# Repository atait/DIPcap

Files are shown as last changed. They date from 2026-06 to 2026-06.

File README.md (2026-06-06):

# DIPcap

A variable capacitor bank built from DIP switches. Six decades of coverage (1 nF to 1 mF) for under $10 to build.

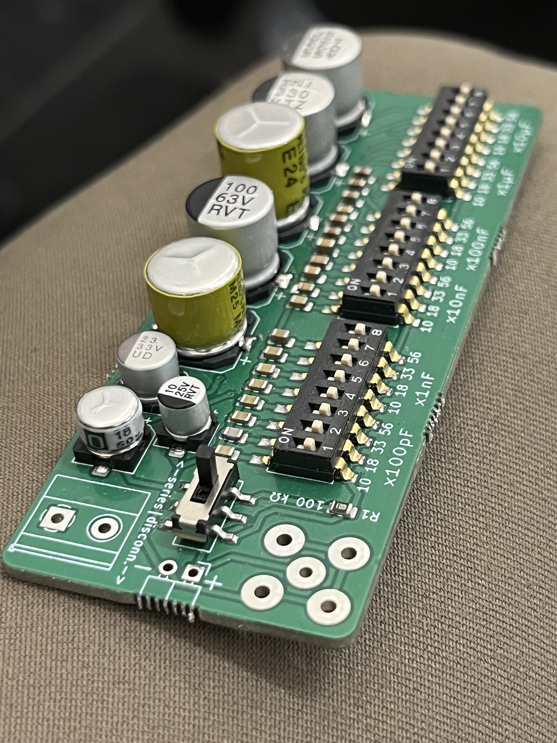
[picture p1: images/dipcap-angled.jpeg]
DIPcap board


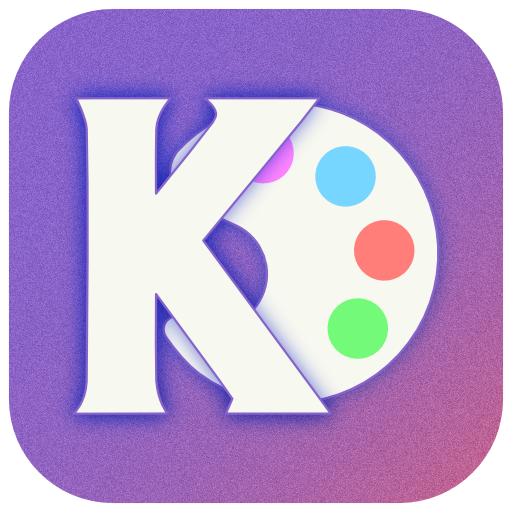
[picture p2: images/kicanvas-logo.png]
Kicanvas icon

[Explore the files on KiCanvas](https://kicanvas.org/?repo=https%3A%2F%2Fgithub.com%2Fatait%2FDIPcap%2Ftree%2Fmain%2Fdipcap-src)

## What it is

DIPcap covers six decades with 24 switches arranged in three groups of eight, using a non-standard but deliberate value series that guarantees full range coverage with the optimal number of switches per decade.

The calibration guarantee is the interesting part: even with ±10% tolerance on individual capacitors, some combination of switches will converge on any target value.

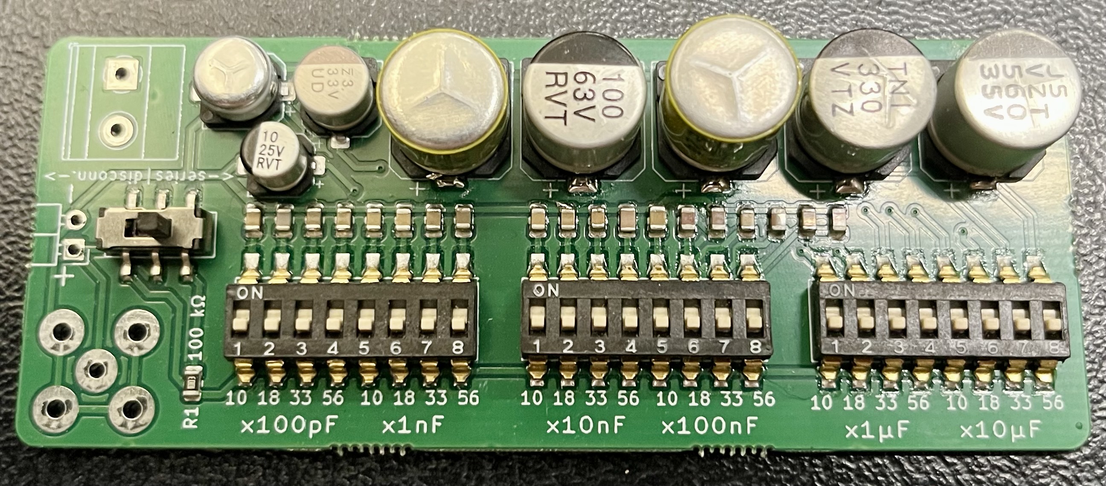
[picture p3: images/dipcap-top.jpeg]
DIPcap board


## Specifications

| Parameter | Value |
|---|---|
| Range | 1 nF – 1,130 µF |
| Max voltage | 0-35V, or ±50V for values < 1 µF |
| Tolerance (dead reckoning) | ±10% |
| Parasitic capacitance (all off) | 28 pF (measured) |
| Output connector | BNC + screw terminal + pin header |
| Cost to build | ~$10/unit (panelized at 8) |

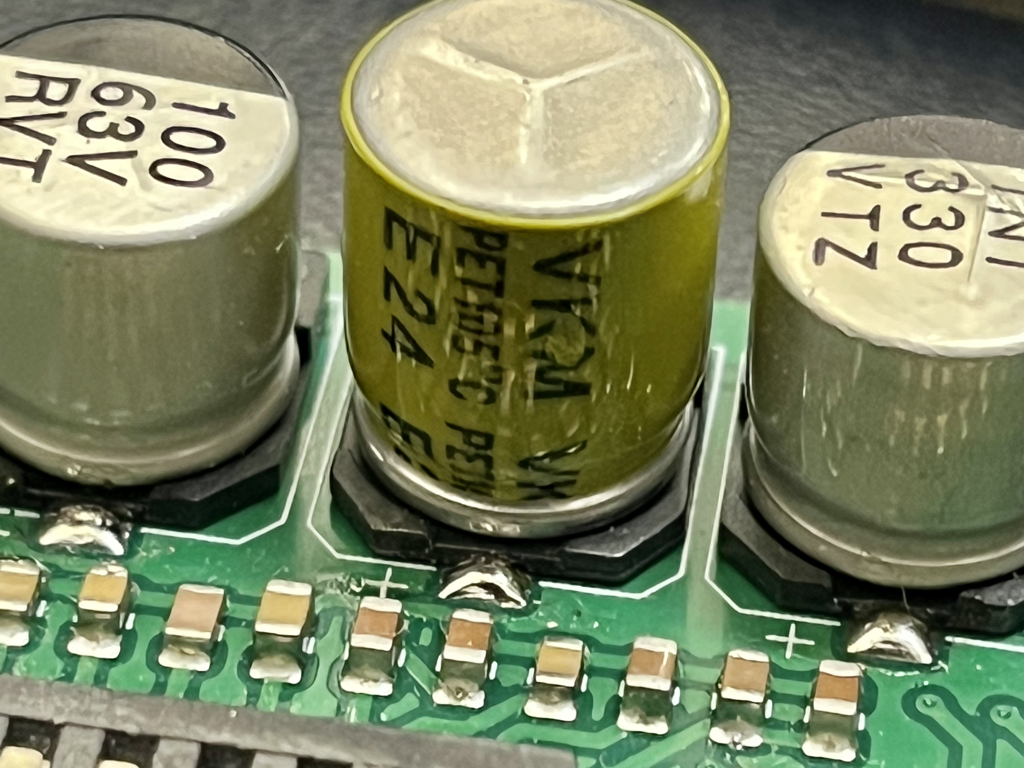
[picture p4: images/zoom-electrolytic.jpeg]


## Why these switch values?

The values per decade are **10, 18, 33, 56** (in units of the decade's base, e.g. ×100pF, ×1nF, etc.). This is not a standard E-series but is drawn from E12 so that common components are available.

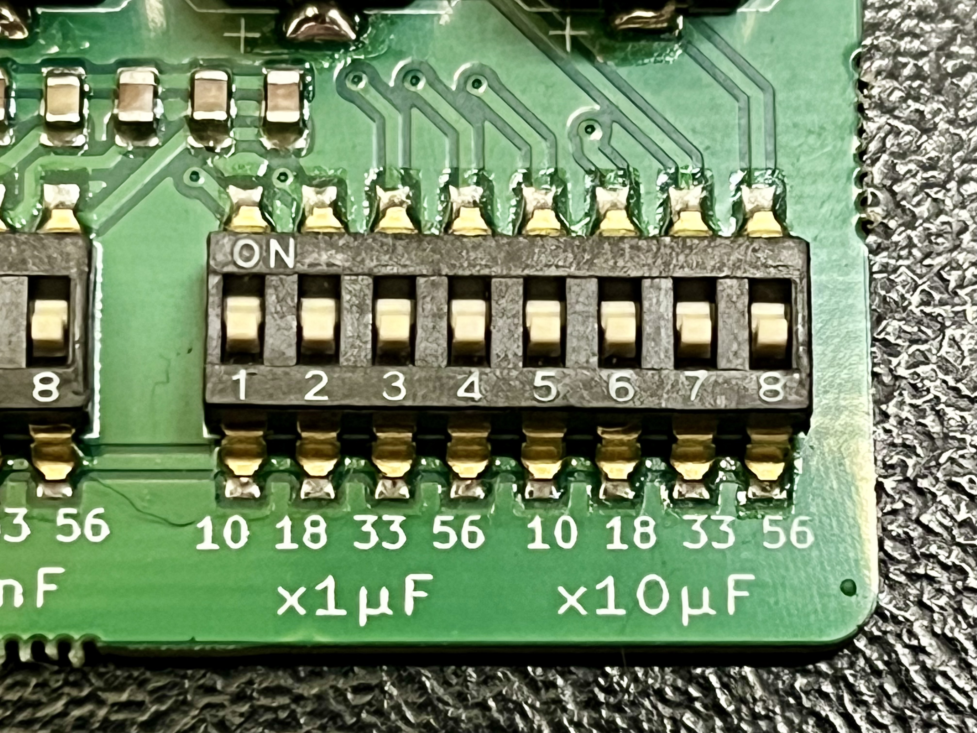
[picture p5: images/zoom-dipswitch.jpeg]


Full coverage means every value between 10–100 (in normalized units) is reachable within ±10% by some switch combination, and the next lower decade handles the remaining gap.

The choice of four switches per decade follows from a coverage argument:

- 2³ = 8 steps per decade — not enough; the gap between steps (100÷8 = 12.5) exceeds the range of the next lower decade group (0–10)
- 2⁴ = 16 steps per decade — sufficient; four is the minimum power-of-2 count that guarantees full coverage

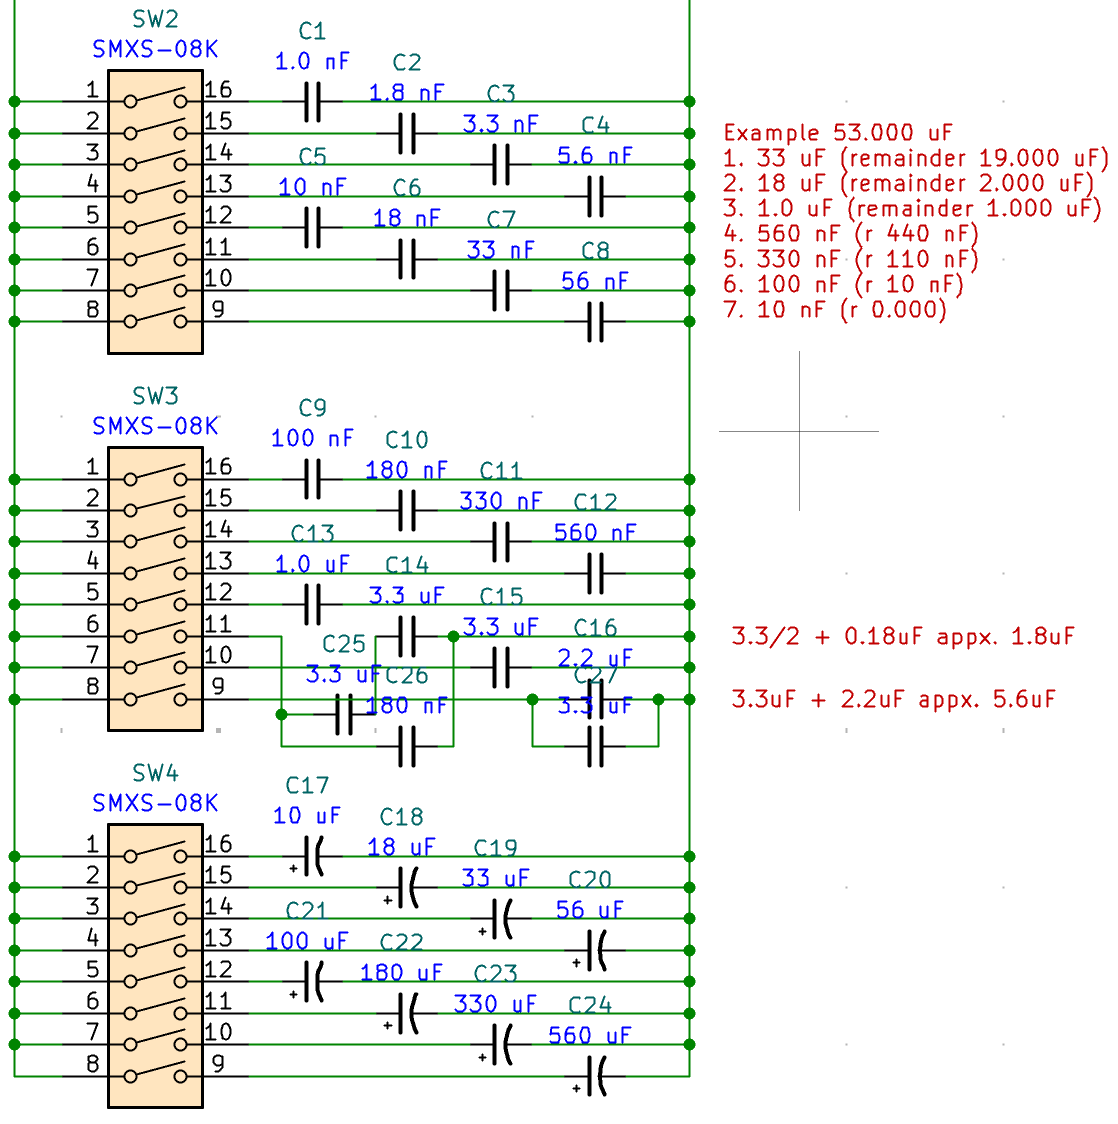
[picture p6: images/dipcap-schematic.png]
Schematic


## Instructions

There are two ways to use DIPcap:
1. Dead reckoning — set by remainder approximation to within ±10%
2. Calibration — engage the series resistor, measure the RC time constant on a scope, and back out the exact capacitance regardless of component tolerance

The instructions are silkscreened on the back of the board.

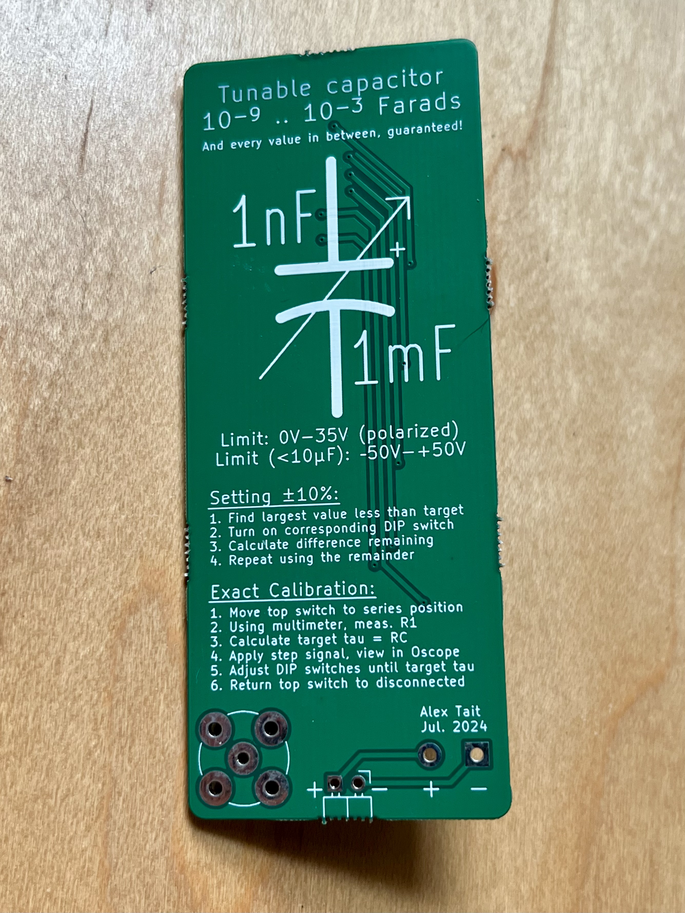
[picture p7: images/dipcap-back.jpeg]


## What's next

**DIPresi** — the same concept applied to resistance. Binary-weighted resistor bank with DIP switches, covering several decades of resistance.

## License

Hardware released under [CERN-OHL-S v2](LICENSE). Design files are the Complete Source as defined by the licence.

© 2026 Alex Tait — source location: https://github.com/atait/dipcap

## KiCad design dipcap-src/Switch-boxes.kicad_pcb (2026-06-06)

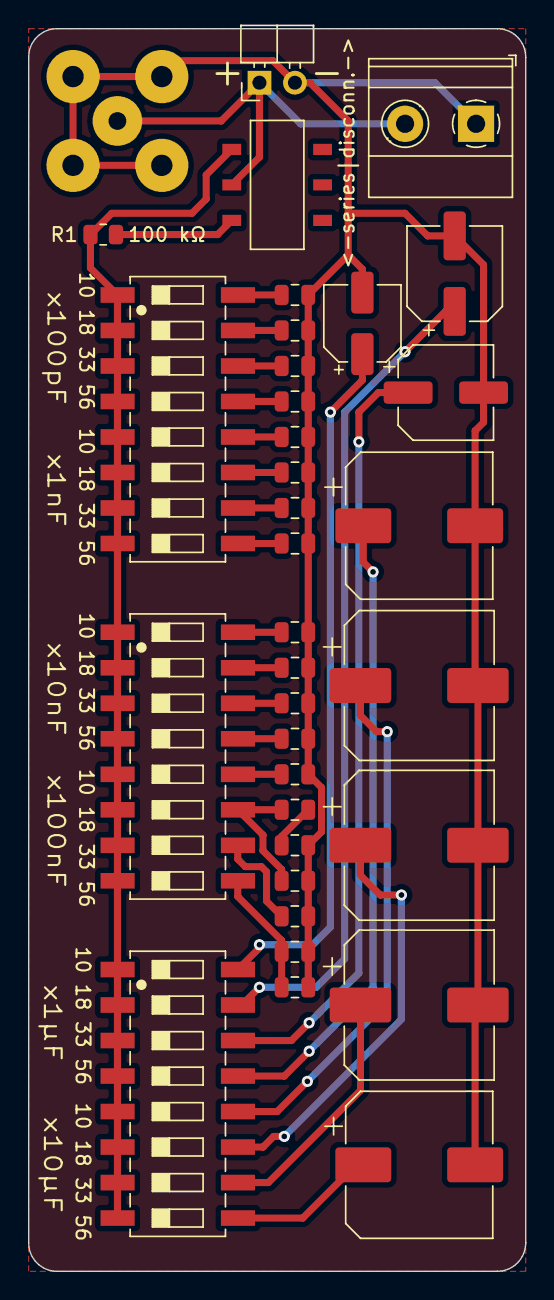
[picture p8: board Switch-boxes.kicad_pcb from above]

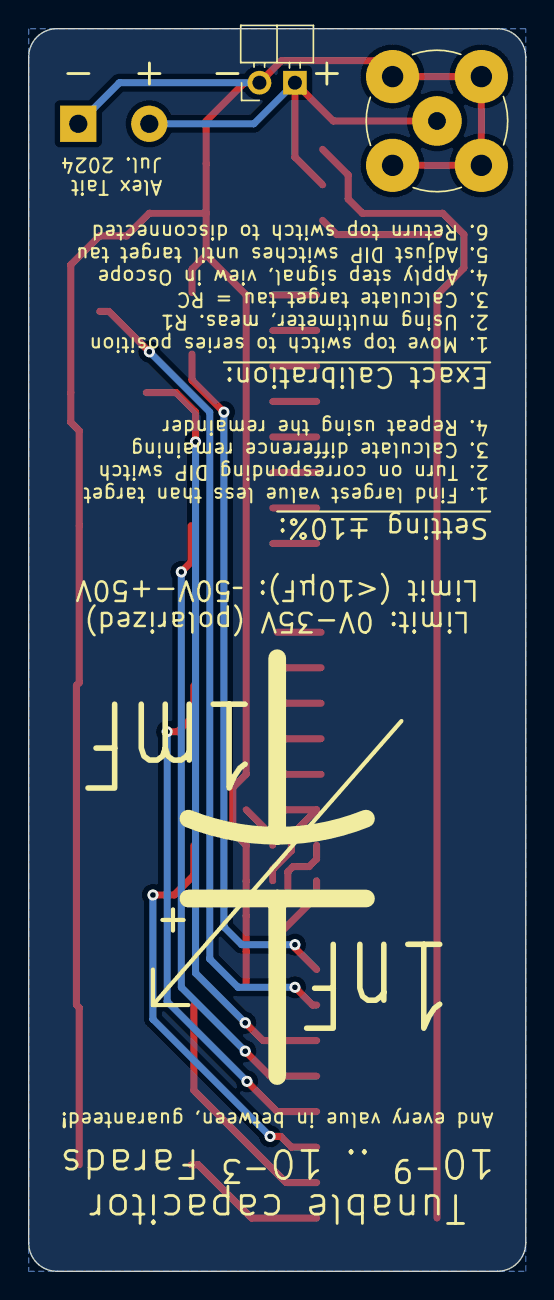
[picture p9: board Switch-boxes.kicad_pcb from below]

Board: 2 copper layers, 35.6 x 88.9 mm, 36 parts (2 on the bottom side), 29 nets.

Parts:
C1: 1.0 nF; C_0805_2012Metric
C2: 1.8 nF; C_0805_2012Metric
C3: 3.3 nF; C_0805_2012Metric
C4: 5.6 nF; C_0805_2012Metric
C5: 10 nF; C_0805_2012Metric
C6: 18 nF; C_0805_2012Metric
C7: 33 nF; C_0805_2012Metric
C8: 56 nF; C_0805_2012Metric
C9: 100 nF; C_0805_2012Metric
C10, C26: 180 nF; C_0805_2012Metric
C11: 330 nF; C_0805_2012Metric
C12: 560 nF; C_0805_2012Metric
C13: 1.0 uF; C_0805_2012Metric
C14, C15, C25, C27: 3.3 uF; C_0805_2012Metric
C16: 2.2 uF; C_0805_2012Metric
C17: 10 uF; CP_Elec_5x5.4
C18: 18 uF; CP_Elec_6.3x5.7
C19: 33 uF; CP_Elec_6.3x5.8
C20: 56 uF; CP_Elec_10x10
C21: 100 uF; CP_Elec_10x10.5
C22: 180 uF; CP_Elec_10x12.5
C23: 330 uF; CP_Elec_10x10.5
C24: 560 uF; CP_Elec_10x10
J1, J3: Conn_01x02; PinHeader_1x02_P2.54mm_Horizontal
J2: BNC; BNC_TEConnectivity_1478204_Vertical
J4: Conn_01x02; TerminalBlock_Phoenix_MKDS-1,5-2-5.08_1x02_P5.08mm_Horizont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
R1: 100 kΩ; R_0805_2012Metric
SW1: SW_Push_DPDT; SW_DPDT_XKB_SS-3235S-L3
SW2, SW3, SW4: SMXS-08K; SW_DIP_SPSTx08_P2.54mm_easyEDA

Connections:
unnamed: C1.1, SW2.16
unnamed: C2.1, SW2.15
unnamed: C3.1, SW2.14
unnamed: C4.1, SW2.13
unnamed: C5.1, SW2.12
unnamed: C6.1, SW2.11
unnamed: C7.1, SW2.10
unnamed: C8.1, SW2.9
unnamed: C9.1, SW3.16
unnamed: C10.1, SW3.15
unnamed: C11.1, SW3.14
unnamed: C12.1, SW3.13
unnamed: C13.1, SW3.12
unnamed: C14.1, C25.2
unnamed: C15.1, SW3.10
unnamed: C16.1, C27.1, SW3.9
unnamed: C17.1, SW4.16
unnamed: C18.1, SW4.15
unnamed: C19.1, SW4.14
unnamed: C20.1, SW4.13
unnamed: C21.1, SW4.12
unnamed: C22.1, SW4.11
unnamed: C23.1, SW4.10
unnamed: C24.1, SW4.9
unnamed: C25.1, C26.1, SW3.11
unnamed: J1.1, J2.1 (In), J4.2, SW1.2 (B)
unnamed: C1.2, C2.2, C3.2, C4.2, C5.2, C6.2, C7.2, C8.2, C9.2, C10.2, C11.2, C12.2, C13.2, C14.2, C15.2, C16.2, C17.2, C18.2, C19.2, C20.2, C21.2, C22.2, C23.2, C24.2, C26.2, C27.2, J1.2, J2.2 (Ext), J4.1
unnamed: R1.1, SW1.3 (C), SW2.1, SW2.2, SW2.3, SW2.4, SW2.5, SW2.6, SW2.7, SW2.8, SW3.1, SW3.2, SW3.3, SW3.4, SW3.5, SW3.6, SW3.7, SW3.8, SW4.1, SW4.2, SW4.3, SW4.4, SW4.5, SW4.6, SW4.7, SW4.8
unnamed: R1.2, SW1.1 (A)

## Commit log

2026-06-06 source files
    [Switch-boxes.kicad_pcb, Switch-boxes.kicad_sch]
2026-06-06 changed path to make room for future spin offs
    [Switch-boxes.kicad_pcb, Switch-boxes.kicad_sch]
